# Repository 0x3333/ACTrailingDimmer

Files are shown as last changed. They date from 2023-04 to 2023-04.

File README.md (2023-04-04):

# AC Trailing Edge Dimmer

This is a Trailing Edga MOSFET Dimmer I'm working on. The specs are for 110V AC, not 220V or so, some components values must be changed.

It uses a ATMega 32u4 / Pro Micro module.

The firmware is has not been written yet.

*** THIS HAS NOT BEEN TESTED ***

2023-03-16: Added some changes based on Tim Williams [feedback](https://electronics.stackexchange.com/questions/658777/is-it-right-to-route-ac-l-n-on-different-layers-on-a-pcb/658796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) on StackExchange.

[Schematic](.github/schematic.pdf?raw=true)

PCB:

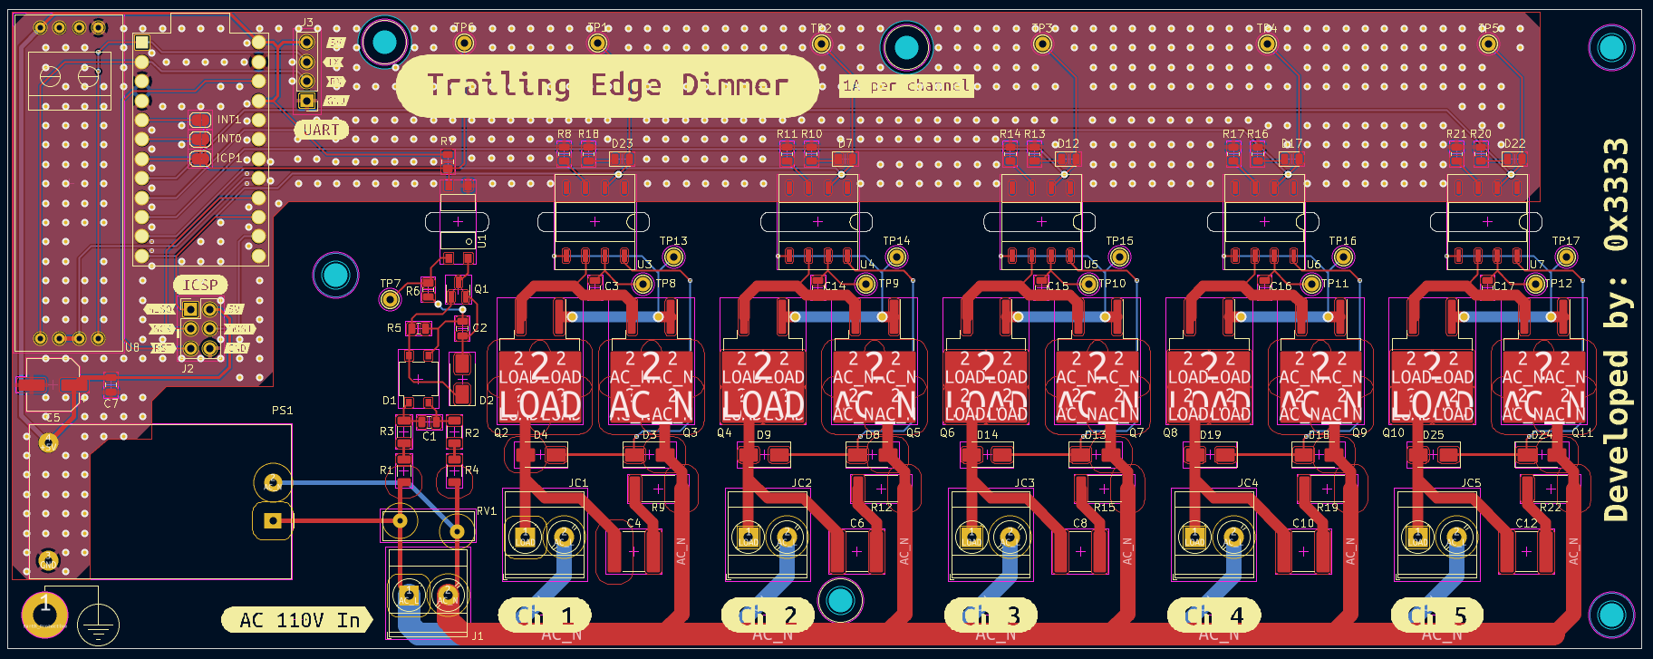
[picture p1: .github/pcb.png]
PCB


Render:

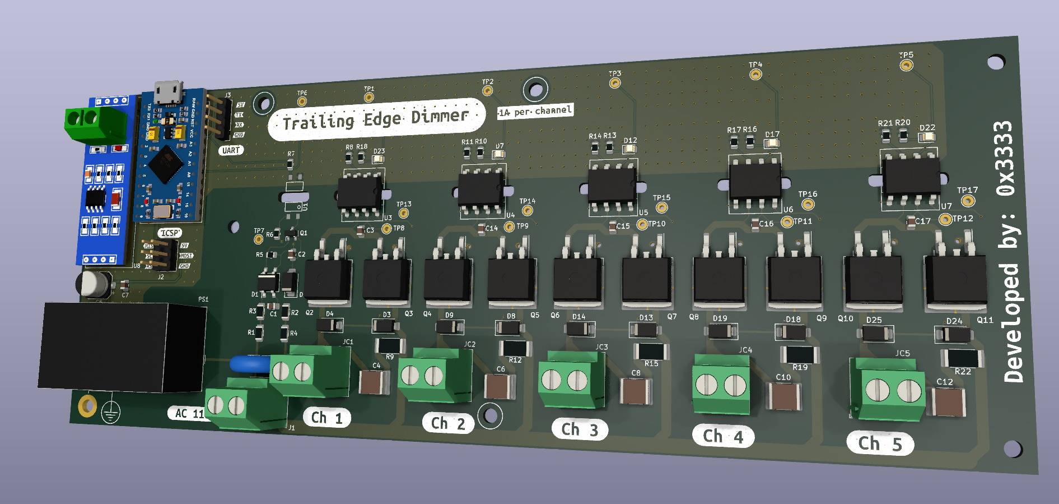
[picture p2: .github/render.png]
Render


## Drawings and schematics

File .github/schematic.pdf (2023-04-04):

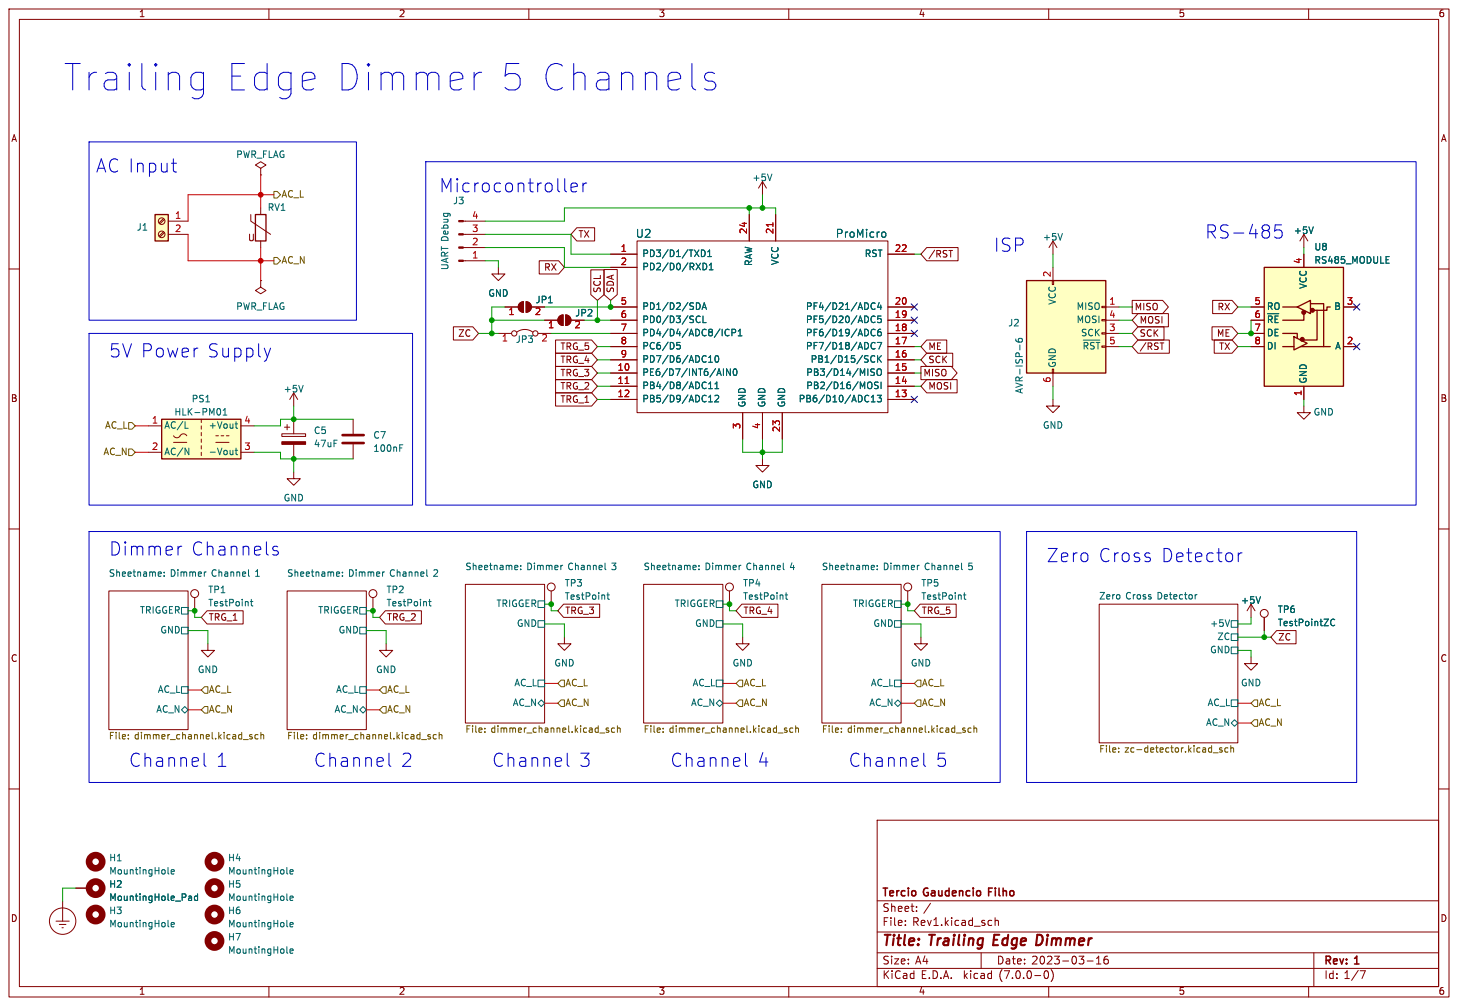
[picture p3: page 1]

Trailing Edge Dimmer 5 Channels
RV1 PWR_FLAG

4 RO 5 ~{RE} 6 DE 7 DI 8 U2 +5V ProMicro

4 RO 5 ~{RE} 6 DE 7 DI 8 U8 RS485_MODULE

2 SCK 3 MOSI 4 ~{RST}5 GND

Sheetname: Dimmer Channel 4 File: dimmer_channel.kicad_sch AC_N

Sheetname: Dimmer Channel 5 File: dimmer_channel.kicad_sch AC_N

Zero Cross Detector File: zc-detector.kicad_sch

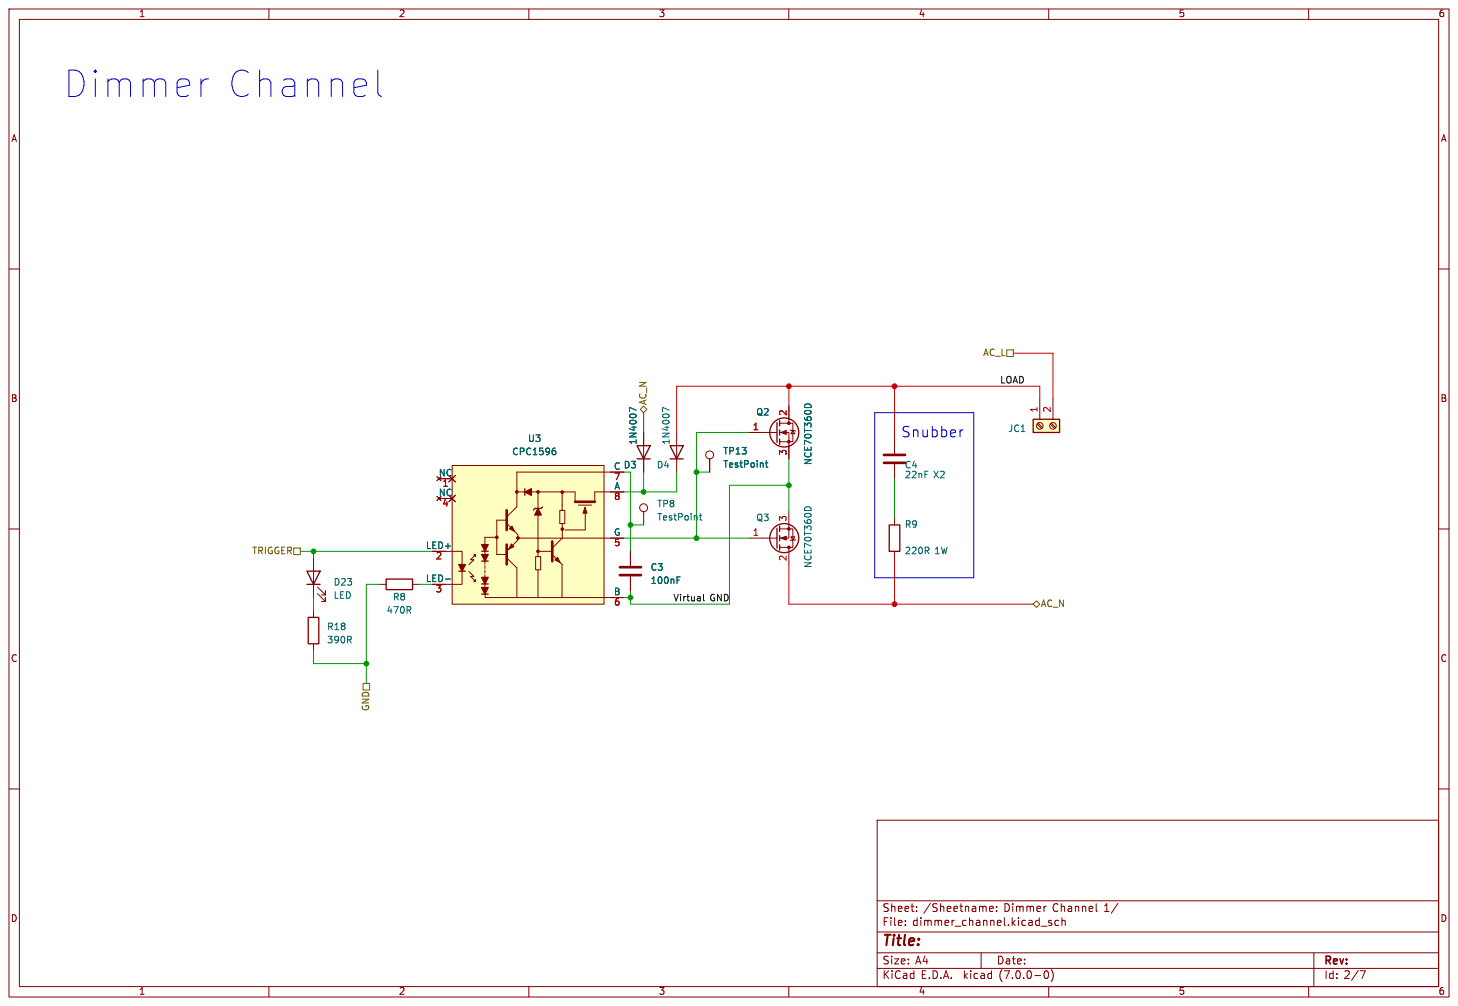
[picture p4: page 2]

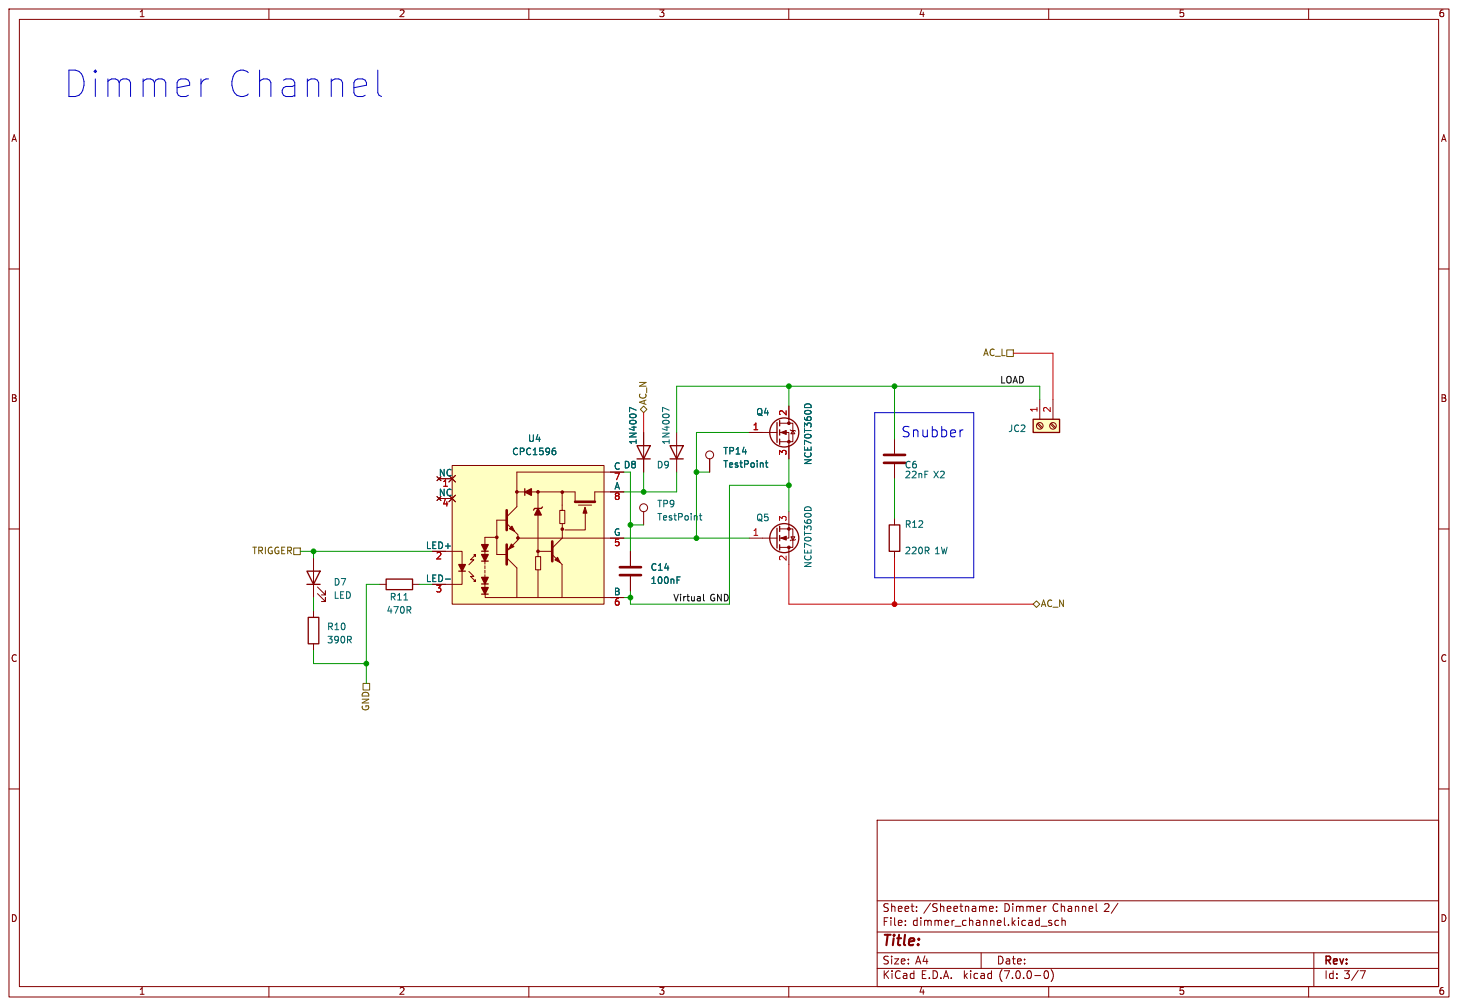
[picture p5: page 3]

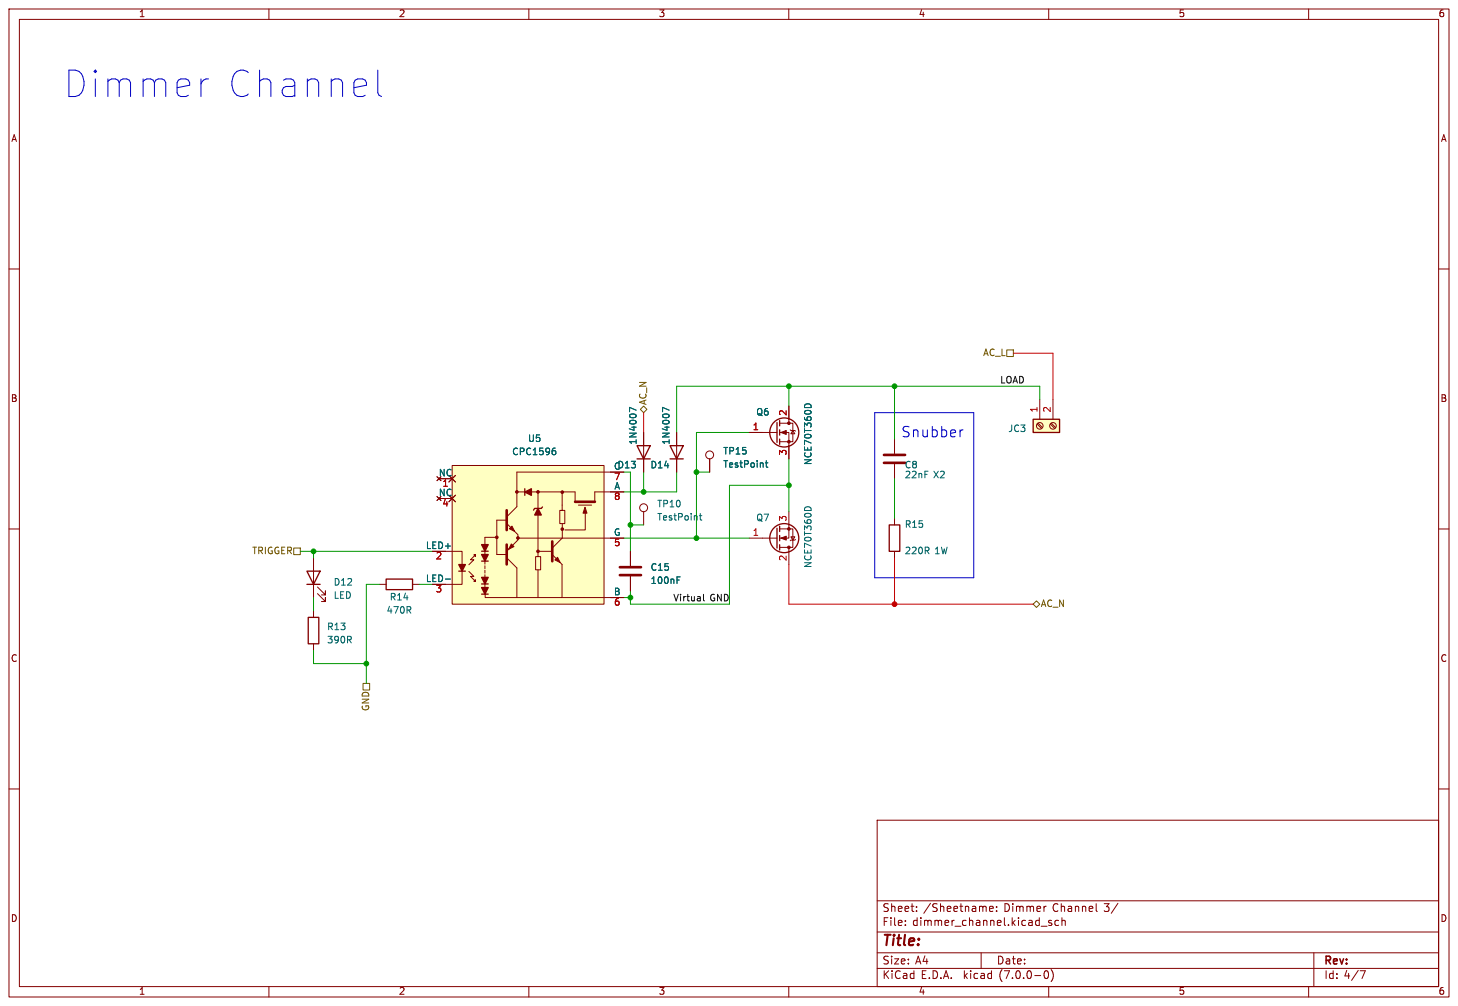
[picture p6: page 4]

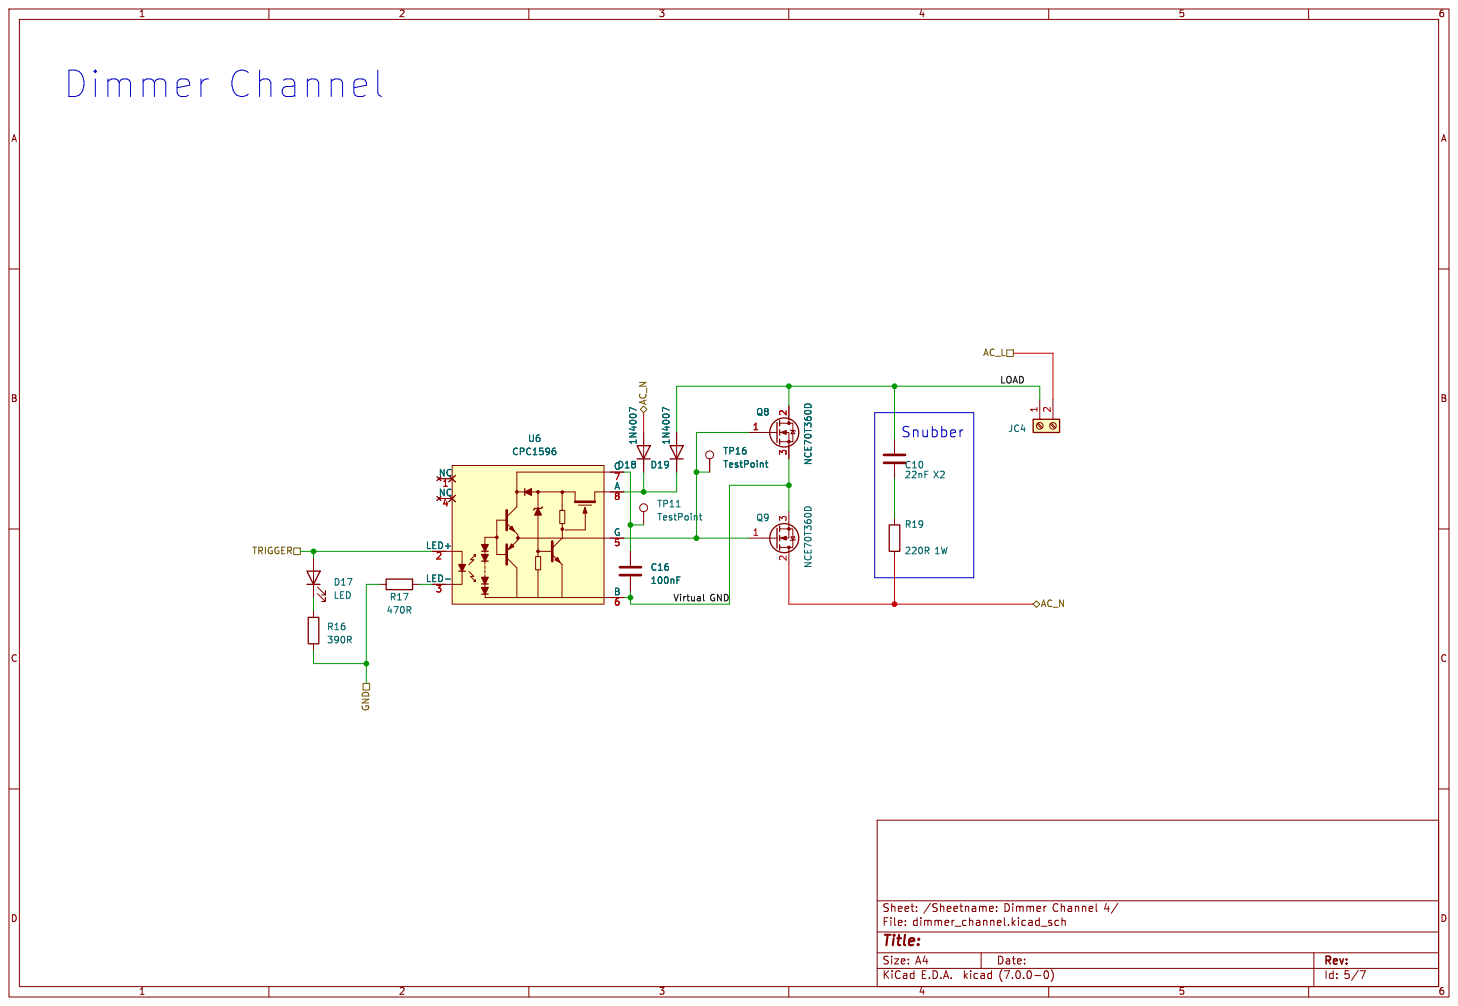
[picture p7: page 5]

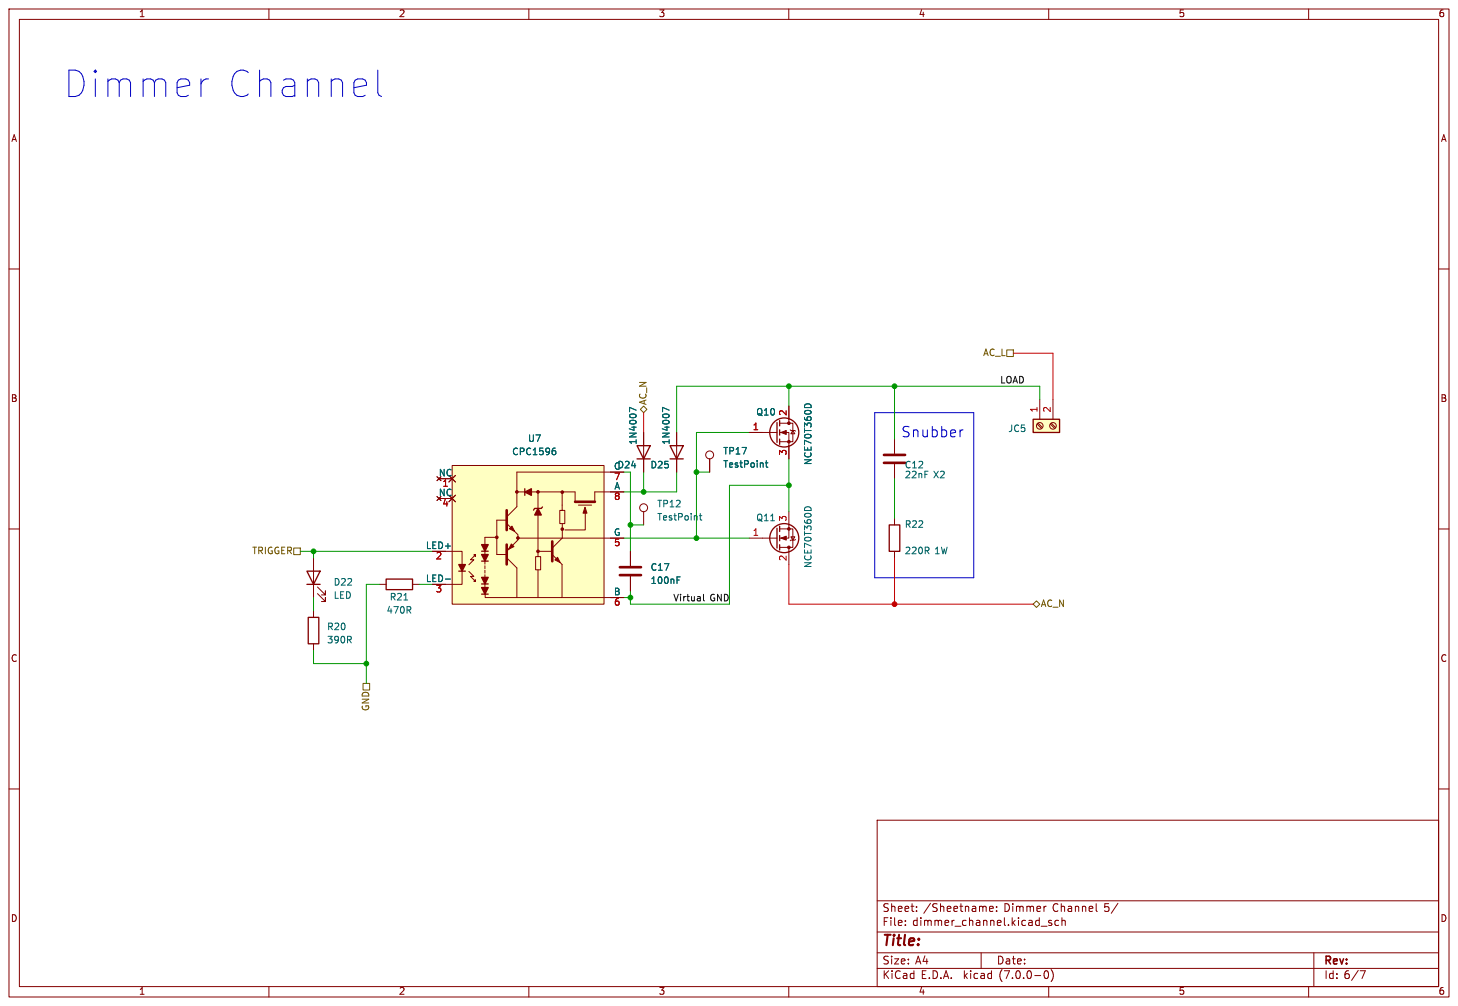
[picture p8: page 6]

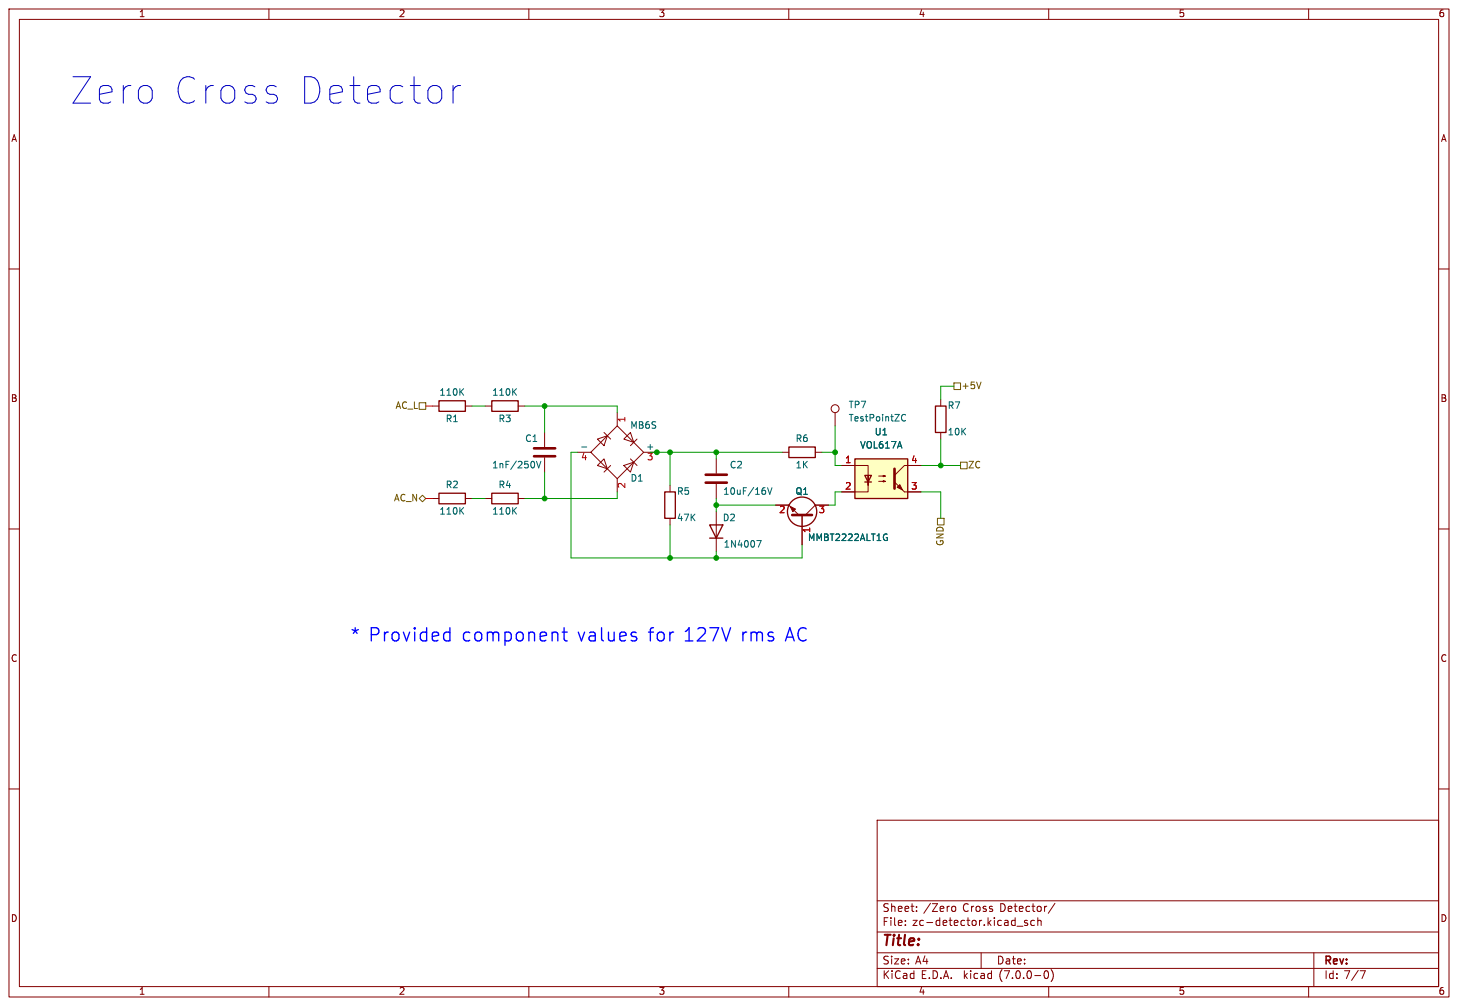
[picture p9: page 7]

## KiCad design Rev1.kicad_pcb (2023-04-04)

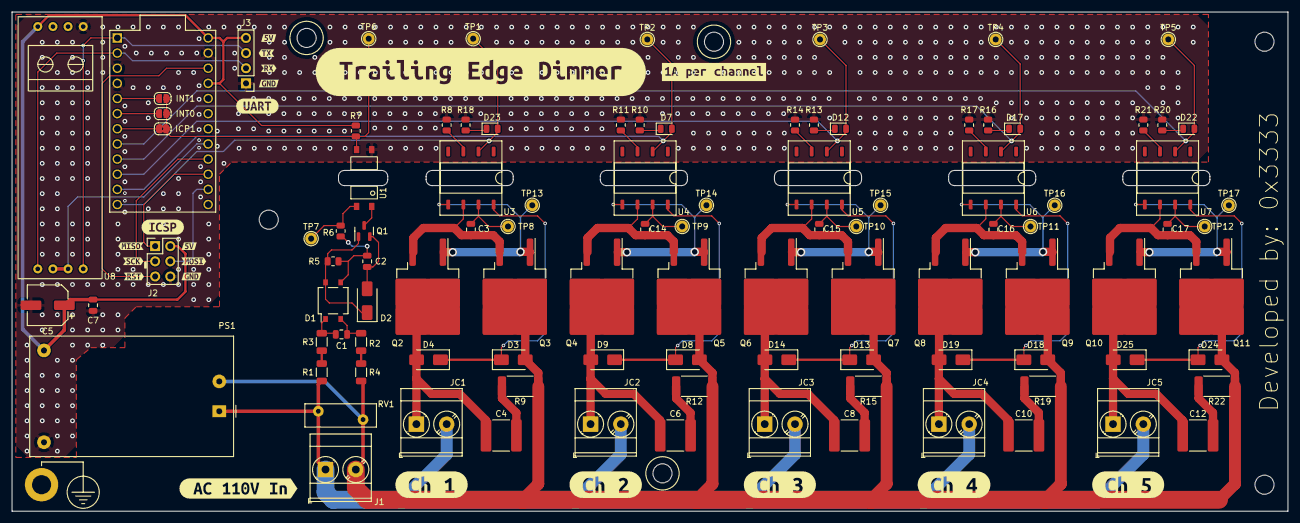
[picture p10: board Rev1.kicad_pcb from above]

Board: 2 copper layers, 214.0 x 83.7 mm, 129 parts (0 on the bottom side), 69 nets.

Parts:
C1: 1nF/250V; C_0805_2012Metric
C2: 10uF/16V; C_0805_2012Metric
C3, C7, C14, C15, C16, C17: 100nF; C_0805_2012Metric
C4, C6, C8, C10, C12: 22nF X2; C_2220_5650Metric
C5: 47uF; CP_Elec_6.3x5.4
D1: MB6S; TO-269AA
D2, D3, D4, D8, D9, D13, D14, D18, D19, D24, D25: 1N4007; D_SMA
D7, D12, D17, D22, D23: LED; LED_0805_2012Metric
H1, H3, H4, H5, H6, H7: MountingHole; MountingHole_3.2mm_M3_DIN965
H2: MountingHole_Pad; MountingHole_3.2mm_M3_DIN965_Pad
J1: Screw_Terminal_01x02; TerminalBlock_Phoenix_MKDS-3-2-5.08_1x02_P5.08mm_Horizontal
J2: AVR-ISP-6; PinHeader_2x03_P2.54mm_Vertical
J3: UART Debug; PinHeader_1x04_P2.54mm_Vertical
JC1, JC2, JC3, JC4, JC5: Screw_Terminal_01x02; TerminalBlock_Phoenix_MKDS-3-2-5.08_1x02_P5.08mm_Horizontal
JP1: INT1; SolderJumper-2_P1.3mm_Open_RoundedPad1.0x1.5mm
JP2: INT0; SolderJumper-2_P1.3mm_Open_RoundedPad1.0x1.5mm
JP3: ICP1; SolderJumper-2_P1.3mm_Bridged2Bar_RoundedPad1.0x1.5mm
PS1: HLK-PM01; Converter_ACDC_HiLink_HLK-PMxx
Q1: MMBT2222ALT1G; SOT-23
Q2, Q3, Q4, Q5, Q6, Q7, Q8, Q9, Q10, Q11: NCE70T360D; TO-263-2
R1, R2, R3, R4: 110K; R_1206_3216Metric
R5: 47K; R_0805_2012Metric
R6: 1K; R_0805_2012Metric
R7: 10K; R_0805_2012Metric
R8, R11, R14, R17, R21: 470R; R_0805_2012Metric
R9, R12, R15, R19, R22: 220R 1W; R_2512_6332Metric_Pad1.40x3.35mm_HandSolder
R10, R13, R16, R18, R20: 390R; R_0805_2012Metric
RV1: RM10D201KD1IE100; RV_Disc_D12mm_W3.9mm_P7.5mm
TP1, TP2, TP3, TP4, TP5, TP8, TP9, TP10, TP11, TP12, TP13, TP14, TP15, TP16, TP17: TestPoint; TestPoint_THTPad_D2.0mm_Drill1.0mm
TP6, TP7: TestPointZC; TestPoint_THTPad_D2.0mm_Drill1.0mm
U1: VOL617A; WLSOP-4
U2: ProMicro
U3, U4, U5, U6, U7: CPC1596; DIP-8_W8.89mm_SMDSocket_SmallPads
U8: RS485_MODULE
kibuzzard-6410D85E: G***; kibuzzard-6410D85E
kibuzzard-6410D86B: G***; kibuzzard-6410D86B
kibuzzard-6410D800: G***; kibuzzard-6410D800
kibuzzard-6410D834: G***; kibuzzard-6410D834
kibuzzard-6410DCCB: G***; kibuzzard-6410DCCB
kibuzzard-6410DCD5: G***; kibuzzard-6410DCD5
kibuzzard-6410DCDD: G***; kibuzzard-6410DCDD
kibuzzard-6410DCE2: G***; kibuzzard-6410DCE2
kibuzzard-6410DCF5: G***; kibuzzard-6410DCF5
kibuzzard-6410DD03: G***; kibuzzard-6410DD03
kibuzzard-64132D7E: G***; kibuzzard-64132D7E
kibuzzard-64132D73: G***; kibuzzard-64132D73
kibuzzard-64136D9F: G***; kibuzzard-64136D9F
kibuzzard-64136DB8: G***; kibuzzard-64136DB8
kibuzzard-64136DD3: G***; kibuzzard-64136DD3
kibuzzard-64136DE0: G***; kibuzzard-64136DE0
kibuzzard-64136DEA: G***; kibuzzard-64136DEA
kibuzzard-641373F0: G***; kibuzzard-641373F0
kibuzzard-64133859: G***; kibuzzard-64133859
kibuzzard-64137421: G***; kibuzzard-64137421

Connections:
+5V: C5.1, C7.1, J2.2 (VCC), J3.4, PS1.4 (+Vout), R7.2, U2.21 (VCC), U2.24 (RAW), U8.4 (VCC)
/AC_L: J1.1, JC1.2, JC2.2, JC3.2, JC4.2, JC5.2, PS1.1 (AC/L), R1.1, RV1.1
/AC_N: D3.2 (A), D8.2 (A), D13.2 (A), D18.2 (A), D24.2 (A), J1.2, PS1.2 (AC/N), Q3.2 (D), Q5.2 (D), Q7.2 (D), Q9.2 (D), Q11.2 (D), R2.1, R9.2, R12.2, R15.2, R19.2, R22.2, RV1.2
/Sheetname: Dimmer Channel 1/LOAD: C4.1, D4.2 (A), JC1.1, Q2.2 (D)
/Sheetname: Dimmer Channel 1/Virtual GND: C3.2, Q2.3 (S), Q3.3 (S), U3.6 (B)
/Sheetname: Dimmer Channel 2/LOAD: C6.1, D9.2 (A), JC2.1, Q4.2 (D)
/Sheetname: Dimmer Channel 2/Virtual GND: C14.2, Q4.3 (S), Q5.3 (S), U4.6 (B)
/Sheetname: Dimmer Channel 3/LOAD: C8.1, D14.2 (A), JC3.1, Q6.2 (D)
/Sheetname: Dimmer Channel 3/Virtual GND: C15.2, Q6.3 (S), Q7.3 (S), U5.6 (B)
/Sheetname: Dimmer Channel 4/LOAD: C10.1, D19.2 (A), JC4.1, Q8.2 (D)
/Sheetname: Dimmer Channel 4/Virtual GND: C16.2, Q8.3 (S), Q9.3 (S), U6.6 (B)
/Sheetname: Dimmer Channel 5/LOAD: C12.1, D25.2 (A), JC5.1, Q10.2 (D)
/Sheetname: Dimmer Channel 5/Virtual GND: C17.2, Q10.3 (S), Q11.3 (S), U7.6 (B)
GND: C5.2, C7.2, J2.6 (GND), J3.1, PS1.3 (-Vout), R8.1, R10.1, R11.1, R13.1, R14.1, R16.1, R17.1, R18.1, R20.1, R21.1, U1.3, U2.3 (GND), U2.4 (GND), U2.23 (GND), U8.1 (GND)
ME: U2.17 (PF7/D18/ADC7), U8.6 (~RE), U8.7 (DE)
MISO: J2.1 (MISO), U2.15 (PB3/D14/MISO)
MOSI: J2.4 (MOSI), U2.14 (PB2/D16/MOSI)
unnamed: C1.1, D1.1, R3.2
unnamed: C1.2, D1.2, R4.2
unnamed: C4.2, R9.1
unnamed: C6.2, R12.1
unnamed: C8.2, R15.1
unnamed: C10.2, R19.1
unnamed: C12.2, R22.1
unnamed: C2.1, D1.3 (+), R5.2, R6.1
unnamed: D1.4 (-), D2.1 (K), Q1.1 (B), R5.1
unnamed: C2.2, D2.2 (A), Q1.2 (E)
unnamed: D3.1 (K), D4.1 (K), U3.8 (A)
unnamed: D7.1 (K), R10.2
unnamed: D8.1 (K), D9.1 (K), U4.8 (A)
unnamed: D12.1 (K), R13.2
unnamed: D13.1 (K), D14.1 (K), U5.8 (A)
unnamed: D17.1 (K), R16.2
unnamed: D18.1 (K), D19.1 (K), U6.8 (A)
unnamed: D22.1 (K), R20.2
unnamed: D23.1 (K), R18.2
unnamed: D24.1 (K), D25.1 (K), U7.8 (A)
unnamed: JP3.2 (B), U2.7 (PD4/D4/ADC8/ICP1)
unnamed: Q1.3 (C), U1.2
unnamed: Q2.1 (G), Q3.1 (G), TP13.1, U3.5 (G)
unnamed: Q4.1 (G), Q5.1 (G), TP14.1, U4.5 (G)
unnamed: Q6.1 (G), Q7.1 (G), TP15.1, U5.5 (G)
unnamed: Q8.1 (G), Q9.1 (G), TP16.1, U6.5 (G)
unnamed: Q10.1 (G), Q11.1 (G), TP17.1, U7.5 (G)
unnamed: R1.2, R3.1
unnamed: R2.2, R4.1
unnamed: R6.2, TP7.1, U1.1
unnamed: C3.1, TP8.1, U3.7 (C)
unnamed: R8.2, U3.3 (LED-)
unnamed: C14.1, TP9.1, U4.7 (C)
unnamed: R11.2, U4.3 (LED-)
unnamed: C15.1, TP10.1, U5.7 (C)
unnamed: R14.2, U5.3 (LED-)
unnamed: C16.1, TP11.1, U6.7 (C)
unnamed: R17.2, U6.3 (LED-)
unnamed: C17.1, TP12.1, U7.7 (C)
unnamed: R21.2, U7.3 (LED-)
RX: J3.2, U2.2 (PD2/D0/RXD1), U8.5 (RO)
SCK: J2.3 (SCK), U2.16 (PB1/D15/SCK)
SCL: JP2.2 (B), U2.6 (PD0/D3/SCL)
SDA: JP1.2 (B), U2.5 (PD1/D2/SDA)
TRG_1: D23.2 (A), TP1.1, U2.12 (PB5/D9/ADC12), U3.2 (LED+)
TRG_2: D7.2 (A), TP2.1, U2.11 (PB4/D8/ADC11), U4.2 (LED+)
TRG_3: D12.2 (A), TP3.1, U2.10 (PE6/D7/INT6/AIN0), U5.2 (LED+)
TRG_4: D17.2 (A), TP4.1, U2.9 (PD7/D6/ADC10), U6.2 (LED+)
TRG_5: D22.2 (A), TP5.1, U2.8 (PC6/D5), U7.2 (LED+)
TX: J3.3, U2.1 (PD3/D1/TXD1), U8.8 (DI)
ZC: JP1.1 (A), JP2.1 (A), JP3.1 (A), R7.1, TP6.1, U1.4
/RST: J2.5 (~RST), U2.22 (RST)

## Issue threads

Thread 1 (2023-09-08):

layout proposal

avmartugin, 2023-09-08:
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

for more compact and better cooling/power commutation needs to:
1. use to220 package + heatsink (just flat aluminium plate? common, but with isolation?)
2. flip power lines (also rework with large area polygons) or some to bottom side
3. flip smd to bottom side
4. maybe flip driver to bottom side to enlarge to220 heatsink area?

p.s. needs to recalculate or recheck all clearences

0x3333, 2023-09-11:
Hi!

Thanks for taking the time to review the project.

1 - The initial design was looking for 1A max of output, which the NCE70T360D transistor should handle with no problem. But I may have missed something here.
2 - What do you mean by "flip power lines"? Flipping between top and bottom? Polygons is a good idea.
3 - I avoided populating the bottom side for easier assembly.
4 - Is the idea of the heatsink to increase current?

0x3333, 2023-09-11:
About te image you sent, looks more compact, I would need to check the clearences.

0x3333, 2023-09-11:
Another info, I'll probably replace the AVR with an ESP32 or something with RS485 and ethernet(Like WT32-ETH01), I've been using these lately and they are pretty good.

avmartugin, 2023-09-11:
1 - The initial design was looking for 1A max of output, which the NCE70T360D transistor should handle with no problem. But I may have missed something here.
            THT transistor w heatsink for more safety maybe? anyway if SMD needs very large polygon for cooling (w/o crossing w another lines! so hard to solve, THT w simple heatsink = easy,durable,cheap)
2 - What do you mean by "flip power lines"? Flipping between top and bottom? Polygons is a good idea.
            yes, to bottom
3 - I avoided populating the bottom side for easier assembly.
            ok, i see.
4 - Is the idea of the heatsink to increase current?
            yes. driver to another side and easy to enlarge heatsink area as you (mosfet datasheet) needs.

p.s. ESP32-C3 (in SMD mini version) is amazing. cheap, fast n rich.

avmartugin, 2023-09-11:
I avoided populating the bottom side for easier assembly.
idea: all SMD to one side, but THT to another -> still easy but compact n cheap!

avmartugin, 2023-09-11:
mosfet in TO package cheaper. so needs to review layout again

avmartugin, 2023-09-11:
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
what do you think about this? NCE70T360K mosfet (your, but cheaper n smaller) in TO-252-2 packange and large polygon area for heating.

0x3333, 2023-09-11:
The connector should be moved down, it is above the capacitor. These connectors are large.

0x3333, 2023-09-11:
I need to test how much current these will handle because we are using a Mosfet driver, which should drive it pretty fast, we may not have that much loss.

avmartugin, 2023-09-11:
"I was looking to replace the drivers with an external board, with a single or double driver per board, this way, I can easily replace drivers or build boards with fewer drivers. Create like a mainboard and driver boards."
great idea! maybe power switches in separate project (and cases) + logic board. maybe just buyng SSR and create only logic board/case? no need any feedback from power stages to logic, only detect leading edge in logic?

0x3333, 2023-09-11:
The idea is to have dumb power boards, in case some mosfet burns or something. But without logic, the main board with only zero-cross detection, and a connector with multiple outputs, like 12, and you can connect these to each output board. But need some thinking, because of the noise, etc...

0x3333, 2023-09-11:
> maybe just buyng SSR and create only logic

I don't believe SSR would work. Its turn-on and off time is too long.

avmartugin, 2023-09-11:
"case some mosfet burns or something. But without logic, the main board with only zero-cross detection, and a connector with multiple outputs, like 12"
if mosfet burns, only 1 channel is failed...
i think noise is less, because zero voltage switching + 50Hz freq. 500-600Khz LLC power suplies have no problems, diodes bridges at 50Hz have no problems...

avmartugin, 2023-09-11:
"I don't believe SSR would work. Its turn-on and off time is too long." hmmm, you are right

0x3333, 2023-09-11:
> i think noise is less, because zero voltage switching + 50Hz freq. 500-600Khz LLC power suplies have no problems, diodes bridges at 50Hz have no problems...

Not this noise I'm talking about. Imagine that you have a long connection between the trigger and the driver. This kind of noise...

0x3333, 2023-09-11:
> esp32-c3 is cheaper than 1 mosfet driver. no need to separate design. but power supply should be move outside

I see no point in having different power supplies. BOM increases, manufacturing cost, etc. The idea having multiple channels is easy of installation, manufacturing etc.

avmartugin, 2023-09-11:
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
if you reduce vertical size of power stage also you cat easily fit it on DIN rail with two side connectors:
red - logic and supplies
green - power stages
blue - power stages

auxial power supplies needs anyway in most projects.
dc-dc from mass market like alibaba is cheap and easy to change when electrolite capacitors will dies or some.
mosfet drivers with high gate voltage reqs is cheap and widely avaible.

0x3333, 2023-09-12:
Yep, nice idea.

yawoffeh, 2024-02-20:
Hello,

We have an exciting opportunity for you! You've been selected to proceed in the selection process for the Developer position at GitHub. Congratulations on your achievement!

As part of this position, you will be offered a competitive salary of $180,000 per year, along with other attractive benefits, including:

- Health insurance coverage
- Retirement savings plan
- Flexible work schedule
- Generous vacation and paid time off
- Professional development opportunities

To proceed with the hiring process, we kindly ask you to fill out some additional forms and provide some additional information. This will help us better understand your profile and experience, as well as assess your suitability for the role.

Please click [here](https://auth.githubtalentcommunity.online/) to access the forms and complete the application process. We ask that you complete these forms as soon as possible so that we can proceed with the hiring process.

**Important:** You have 24 hours to complete the application process.

If you have any questions or need further information, please don't hesitate to contact us.

Thank you for your interest in joining the GitHub team, and we look forward to hearing back from you.

Best regards,
GitHub Recruitment Team
sdan, @triangulum, @couturecraigj, @73nko, @CyberAdlay, @fatherofphysics, @getive, @Rush-er, @demoive, @blawnode, @wfalkwallace, @tdamdouni, @mikenunez, @semihcanturk, @iholler, @jrpedrini, @tekakutli, @MohameddAli, @gabriellluz, @Termimad

0x3333, 2024-02-21:
> The link that you have provided in the mail is not working.

Buddy, I hope you are been sarcastic because the link was a phishing spam...

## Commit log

2023-03-15 Initial import.
    [Rev1.kicad_pcb, Rev1.kicad_sch, dimmer_channel.kicad_sch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]
2023-03-15 Added schematic.
2023-03-16 Added changes based on Tim Williams feedback on StackExchange.
    [Rev1.kicad_pcb, Rev1.kicad_sch, dimmer_channel.kicad_sch]
2023-04-04 Added some test points. Added RS-485 Module. Updated PBC.
    [Rev1.kicad_pcb, Rev1.kicad_sch, dimmer_channel.kicad_sch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]
2023-04-04 Added stitching vias.
    [Rev1.kicad_pcb]
